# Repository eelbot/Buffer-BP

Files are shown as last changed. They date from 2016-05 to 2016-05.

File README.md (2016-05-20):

# Buffer Booster Pack
## Overview
The Buffer Booster Pack is a simple Booster Pack for TI's LaunchPad development ecosystem that connects eight 5V inputs and eight 5V outputs to the 3.3V inputs and outputs of the LaunchPad. There are indicators and screw terminal connections for each input, as well as screw terminals connections for 5V and GND, to easily interface with proto-typed circuits.

## Pinout
The Buffer Booster Pack is made for a 40-pin booster pack, and follows the Booster Pack Standard. The external input and output numbering is shown on the board.

| External Input | Booster Pack Pin # | | External Output | Booster Pack Pin # |
| :---: | :---: | :--: | :---: | :---: |
| 1 | 7 | | 1 | 38 |
| 2 | 8 | | 2 | 37 |
| 3 | 9 | | 3 | 15 |
| 4 | 10 | | 4 | 14 |
| 5 | 5 | | 5 | 34 |
| 6 | 39 | | 6 | 13 |
| 7 | 40 | | 7 | 12 |
| 8 | 19 | | 8 | 11 |

## Firmware Examples
Two examples are included in the firmware folder. There is one for Energia, which uses standard Booster Pack pinouts, and the other is for the F28069 LaunchPad with Code Composer Studio.

## Power
The Buffer Booster Pack supplies 3.3V to the 3V3 pin of the target Launchpad. The 5V pin is not connected, and the external DC Jack must be connected in order for the Booster Pack to function correctly.

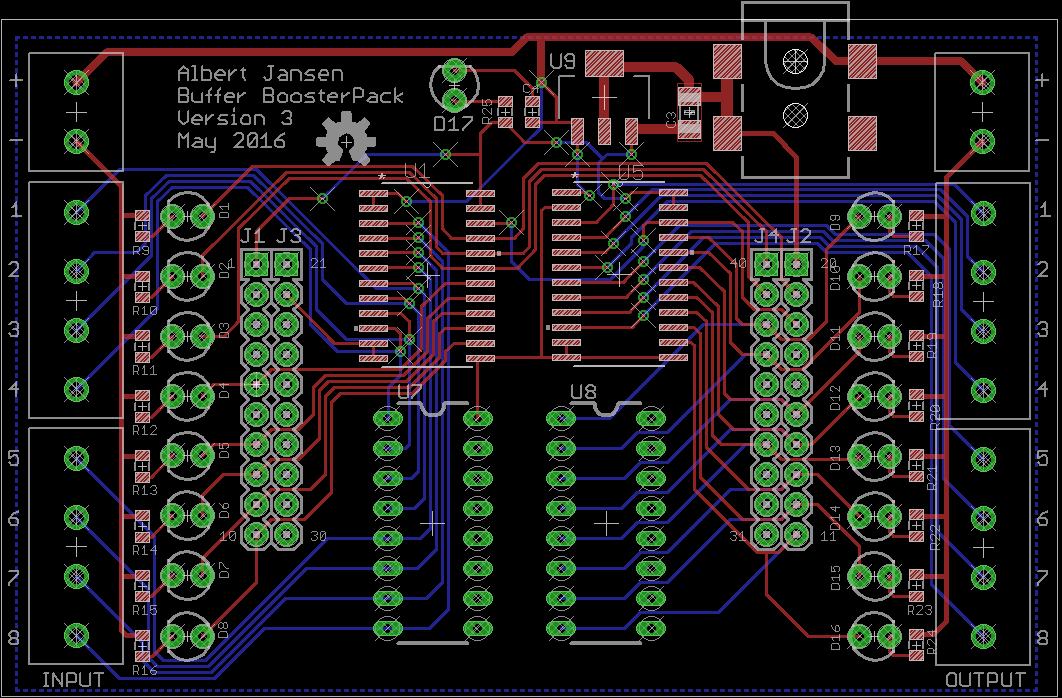
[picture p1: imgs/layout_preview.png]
Board Layout


## To-Do
- Final hardware tests (need to wait until boards arrive)

## License
<br>
This work is licensed under a [Creative Commons Attribution-ShareAlike 3.0 Unported License](http://creativecommons.org/licenses/by-sa/3.0/)

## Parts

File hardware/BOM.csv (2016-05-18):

Part Name | Package | Quantity | Digikey Part Number
2x10 0.1" Female Headers | PTH | 2 | S6106-ND
3mm Blue LED (2mA) | PTH | 17 | 754-1914-ND
330 Resistor | 805 | 17 | RMCF0805JT330RCT-ND
0.47uF Capacitor | 805 | 1 | 399-8100-1-ND
33uF Capacitor | 1206 | 1 | 445-4060-1-ND
1x2 0.2" Screw Terminal | PTH | 2 | ED2609-ND
1x4 0.2" Screw Terminal | PTH | 4 | ED2611-ND
5.5x2.1 Barrel Power Jack | SMD | 1 | CP-002AHPJCT-ND
5V-3.3V LDO | SOT223 | 1 | LM3940IMPX-3.3/NOPBCT-ND
56k Resistor Array (8) | DIP | 2 | 4116R-1-563LF-ND

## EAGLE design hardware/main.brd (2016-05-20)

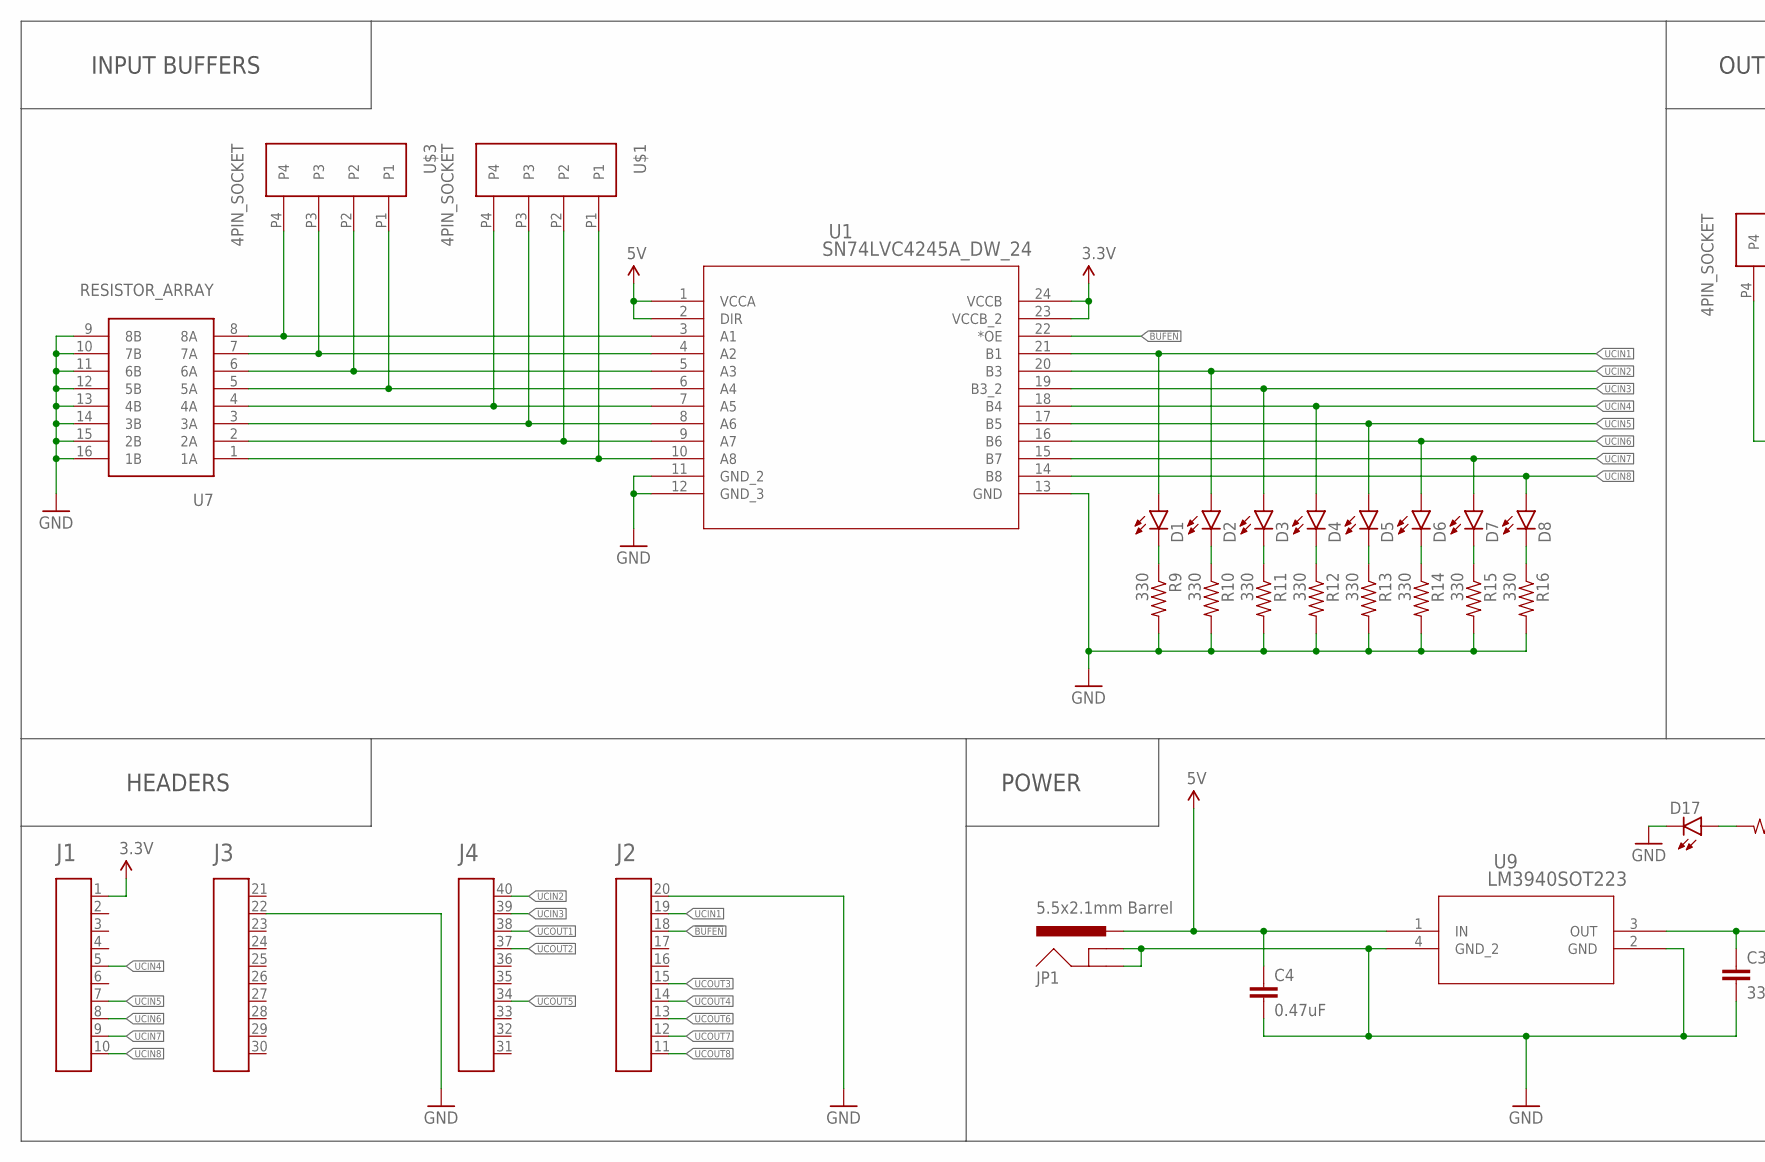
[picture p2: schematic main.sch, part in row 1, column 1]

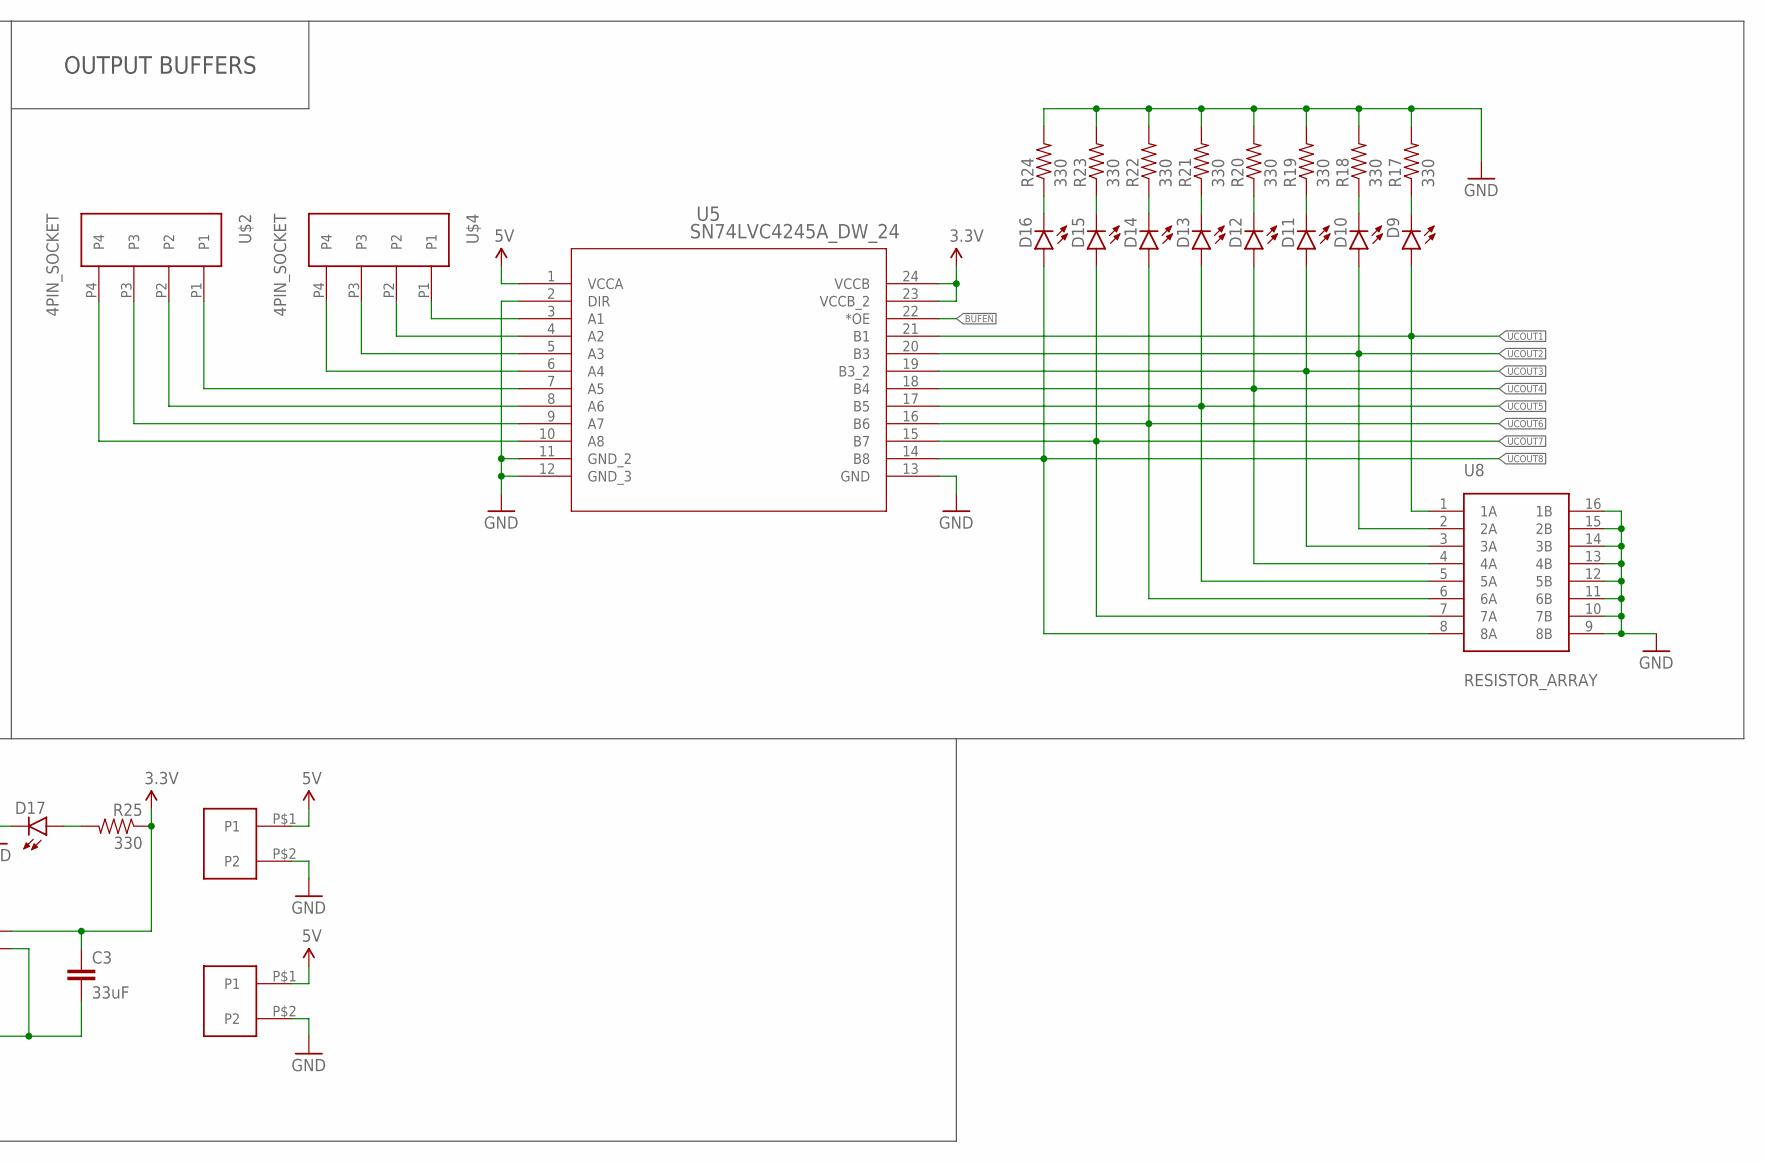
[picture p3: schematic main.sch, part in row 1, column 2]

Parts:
A1: HEADER4X10-BOOSTERPACK; 4X10-BOOSTERPACK
C3: 33uF; 1206
C4: 0.47uF; 0805
D1, D2, D3, D4, D5, D6, D7, D8, D9, D10, D11, D12, D13, D14, D15, D16, D17: LED3MM
JP1: 5.5x2.1mm Barrel; POWER_JACK_SMD
R9, R10, R11, R12, R13, R14, R15, R16, R17, R18, R19, R20, R21, R22, R23, R24, R25: 330; 0805
U1, U5: SN74LVC4245A_DW_24; DW24
U7, U8: RESISTOR_ARRAY; DIL16
U9: LM3940SOT223; DCY
U$1, U$2, U$3, U$4: 4PIN_SOCKET; CONN-4PIN
U$5, U$6: 2PIN_SOCKET; CONN-2PIN

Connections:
3.3V: A1.1, C3.1, R25.1, U1.23 (VCCB_2), U1.24 (VCCB), U5.23 (VCCB_2), U5.24 (VCCB), U9.3 (OUT)
5V: C4.1, JP1.VIN0 (PWR), U1.1 (VCCA), U1.2 (DIR), U5.1 (VCCA), U9.1 (IN), U$5.P$1 (P1), U$6.P$1 (P1)
!BUFEN!: A1.18, U1.22 (*OE), U5.22 (*OE)
GND: A1.20, A1.22, C3.2, C4.2, D17.K (C), JP1.GND (GNDBREAK), JP1.P$4 (GND), R9.2, R10.2, R11.2, R12.2, R13.2, R14.2, R15.2, R16.2, R17.2, R18.2, R19.2, R20.2, R21.2, R22.2, R23.2, R24.2, U1.11 (GND_2), U1.12 (GND_3), U1.13 (GND), U5.2 (DIR), U5.11 (GND_2), U5.12 (GND_3), U5.13 (GND), U7.9 (8B), U7.10 (7B), U7.11 (6B), U7.12 (5B), U7.13 (4B), U7.14 (3B), U7.15 (2B), U7.16 (1B), U8.9 (8B), U8.10 (7B), U8.11 (6B), U8.12 (5B), U8.13 (4B), U8.14 (3B), U8.15 (2B), U8.16 (1B), U9.2 (GND), U9.4 (GND_2), U$5.P$2 (P2), U$6.P$2 (P2)
unnamed: U1.10 (A8), U7.1 (1A), U$1.P1
unnamed: U1.9 (A7), U7.2 (2A), U$1.P2
unnamed: U1.8 (A6), U7.3 (3A), U$1.P3
unnamed: U1.7 (A5), U7.4 (4A), U$1.P4
unnamed: U1.6 (A4), U7.5 (5A), U$3.P1
unnamed: U1.5 (A3), U7.6 (6A), U$3.P2
unnamed: U1.4 (A2), U7.7 (7A), U$3.P3
unnamed: U1.3 (A1), U7.8 (8A), U$3.P4
unnamed: D1.K (C), R9.1
unnamed: D2.K (C), R10.1
unnamed: D3.K (C), R11.1
unnamed: D4.K (C), R12.1
unnamed: D5.K (C), R13.1
unnamed: D6.K (C), R14.1
unnamed: D7.K (C), R15.1
unnamed: D8.K (C), R16.1
unnamed: U5.3 (A1), U$4.P1
unnamed: U5.4 (A2), U$4.P2
unnamed: U5.5 (A3), U$4.P3
unnamed: U5.6 (A4), U$4.P4
unnamed: U5.7 (A5), U$2.P1
unnamed: U5.8 (A6), U$2.P2
unnamed: U5.9 (A7), U$2.P3
unnamed: U5.10 (A8), U$2.P4
unnamed: D9.K (C), R17.1
unnamed: D10.K (C), R18.1
unnamed: D11.K (C), R19.1
unnamed: D12.K (C), R20.1
unnamed: D13.K (C), R21.1
unnamed: D14.K (C), R22.1
unnamed: D15.K (C), R23.1
unnamed: D16.K (C), R24.1
unnamed: D17.A, R25.2
UCIN1: A1.19, D1.A, U1.21 (B1)
UCIN2: A1.40, D2.A, U1.20 (B3)
UCIN3: A1.39, D3.A, U1.19 (B3_2)
UCIN4: A1.5, D4.A, U1.18 (B4)
UCIN5: A1.7, D5.A, U1.17 (B5)
UCIN6: A1.8, D6.A, U1.16 (B6)
UCIN7: A1.9, D7.A, U1.15 (B7)
UCIN8: A1.10, D8.A, U1.14 (B8)
UCOUT1: A1.38, D9.A, U5.21 (B1), U8.1 (1A)
UCOUT2: A1.37, D10.A, U5.20 (B3), U8.2 (2A)
UCOUT3: A1.15, D11.A, U5.19 (B3_2), U8.3 (3A)
UCOUT4: A1.14, D12.A, U5.18 (B4), U8.4 (4A)
UCOUT5: A1.34, D13.A, U5.17 (B5), U8.5 (5A)
UCOUT6: A1.13, D14.A, U5.16 (B6), U8.6 (6A)
UCOUT7: A1.12, D15.A, U5.15 (B7), U8.7 (7A)
UCOUT8: A1.11, D16.A, U5.14 (B8), U8.8 (8A)

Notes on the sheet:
INPUT BUFFERS
HEADERS
OUTPUT BUFFERS
POWER

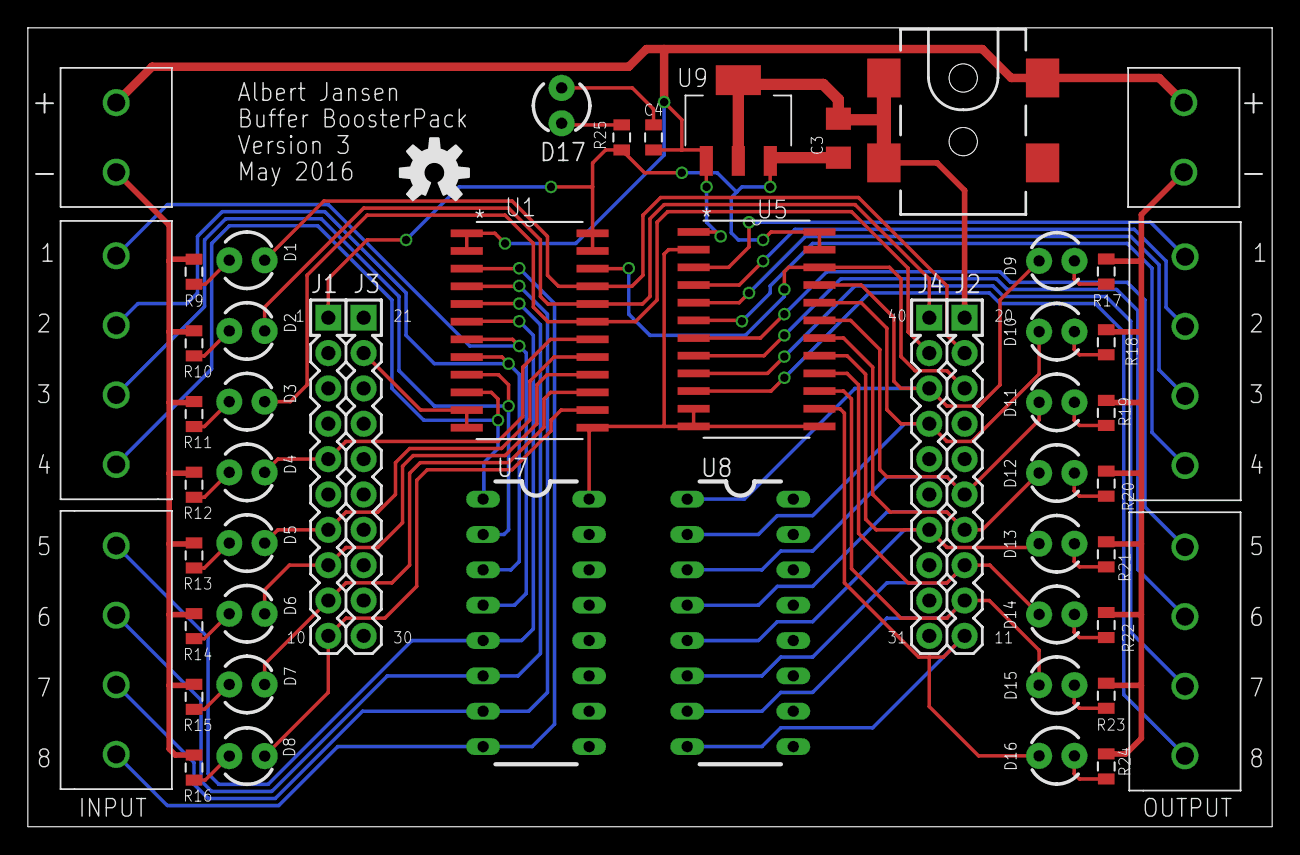
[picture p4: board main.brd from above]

Board: 2 copper layers, 89.4 x 57.4 mm, 50 parts (0 on the bottom side), 53 nets.

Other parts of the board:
U$7: OSHW-LOGO-M

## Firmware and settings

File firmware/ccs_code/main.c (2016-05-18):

#include "DSP28x_Project.h"

/*
 * This program puts the state of the input on the respective output,
 * e.g., if input 4 is high, input 5 is high. The pins are defined from
 * 1-8, e.g. GPIO18 is input 1, GPIO22 is input 2, etc.
 */

void main(void) {

	// Pin configuration
	EALLOW;

	// Inputs
	GpioCtrlRegs.GPADIR.bit.GPIO18 = 0;
	GpioCtrlRegs.GPADIR.bit.GPIO22 = 0;
	GpioCtrlRegs.GPBDIR.bit.GPIO33 = 0;
	GpioCtrlRegs.GPBDIR.bit.GPIO32 = 0;

	GpioCtrlRegs.GPADIR.bit.GPIO12 = 0;
	GpioCtrlRegs.GPADIR.bit.GPIO1 = 0;
	GpioCtrlRegs.GPADIR.bit.GPIO0 = 0;
	GpioCtrlRegs.GPADIR.bit.GPIO19 = 0;

	// Outputs
	GpioCtrlRegs.GPADIR.bit.GPIO2 = 1;
	GpioCtrlRegs.GPADIR.bit.GPIO3 = 1;
	GpioCtrlRegs.GPADIR.bit.GPIO16 = 1;
	GpioCtrlRegs.GPADIR.bit.GPIO17 = 1;

	GpioCtrlRegs.GPADIR.bit.GPIO13 = 1;
	GpioCtrlRegs.GPBDIR.bit.GPIO50 = 1;
	GpioCtrlRegs.GPBDIR.bit.GPIO51 = 1;
	GpioCtrlRegs.GPBDIR.bit.GPIO55 = 1;
	EDIS;
	
	while(1){
		// Check input 1
		if(GpioDataRegs.GPADAT.bit.GPIO18){
			GpioDataRegs.GPASET.bit.GPIO2 = 1;
		}
		else{
			GpioDataRegs.GPACLEAR.bit.GPIO2 = 1;
		}

		// Check input 2
		if(GpioDataRegs.GPADAT.bit.GPIO22){
			GpioDataRegs.GPASET.bit.GPIO3 = 1;
		}
		else{
			GpioDataRegs.GPACLEAR.bit.GPIO3 = 1;
		}

		// Check input 3
		if(GpioDataRegs.GPBDAT.bit.GPIO33){
			GpioDataRegs.GPASET.bit.GPIO16 = 1;
		}
		else{
			GpioDataRegs.GPACLEAR.bit.GPIO16 = 1;
		}

		// Check input 4
		if(GpioDataRegs.GPBDAT.bit.GPIO32){
			GpioDataRegs.GPASET.bit.GPIO17 = 1;
		}
		else{
			GpioDataRegs.GPACLEAR.bit.GPIO17 = 1;
		}

		// Check input 5
		if(GpioDataRegs.GPADAT.bit.GPIO12){
			GpioDataRegs.GPASET.bit.GPIO13 = 1;
		}
		else{
			GpioDataRegs.GPACLEAR.bit.GPIO13 = 1;
		}

		// Check input 6
		if(GpioDataRegs.GPADAT.bit.GPIO1 == 1){
			GpioDataRegs.GPBSET.bit.GPIO50 = 1;
		}
		else{
			GpioDataRegs.GPBCLEAR.bit.GPIO50 = 1;
		}

		// Check input 7
		if(GpioDataRegs.GPADAT.bit.GPIO18 == 1){
			GpioDataRegs.GPBSET.bit.GPIO51 = 1;
		}
		else{
			GpioDataRegs.GPBCLEAR.bit.GPIO51 = 1;
		}

		// Check input 8
		if(GpioDataRegs.GPADAT.bit.GPIO19 == 1){
			GpioDataRegs.GPBSET.bit.GPIO55 = 1;
		}
		else{
			GpioDataRegs.GPBCLEAR.bit.GPIO55 = 1;
		}
	}
}

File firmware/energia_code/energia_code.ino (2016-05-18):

// Pin definitions for easy sketch modification
// INPUTS
const int in1 = 7;
const int in2 = 8;
const int in3 = 9;
const int in4 = 10;
const int in5 = 5;
const int in6 = 39;
const int in7 = 40;
const int in8 = 19;

// OUTPUTS
const int out1 = 38;
const int out2 = 37;
const int out3 = 15;
const int out4 = 14;
const int out5 = 34;
const int out6 = 13;
const int out7 = 12;
const int out8 = 11;

// Buffer enable
const int buffer_enable = 18;


void setup()
{
  // Turn off buffers to start (buffer_enable is active low)
  pinMode(buffer_enable, OUTPUT);
  digitalWrite(buffer_enable, HIGH);
  
  // Inputs
  pinMode(in1, INPUT);
  pinMode(in2, INPUT);
  pinMode(in3, INPUT);
  pinMode(in4, INPUT);
  pinMode(in5, INPUT);
  pinMode(in6, INPUT);
  pinMode(in7, INPUT);
  pinMode(in8, INPUT);
  
  // Outputs
  pinMode(out1, OUTPUT);
  pinMode(out2, OUTPUT);
  pinMode(out3, OUTPUT);
  pinMode(out4, OUTPUT);
  pinMode(out5, OUTPUT);
  pinMode(out6, OUTPUT);
  pinMode(out7, OUTPUT);
  pinMode(out8, OUTPUT);
  
  // Initialize all outputs to 0
  digitalWrite(out1, LOW);
  digitalWrite(out2, LOW);
  digitalWrite(out3, LOW);
  digitalWrite(out4, LOW);
  digitalWrite(out5, LOW);
  digitalWrite(out6, LOW);
  digitalWrite(out7, LOW);
  digitalWrite(out8, LOW);
  
  // Enable buffers
  digitalWrite(buffer_enable, LOW);
}

void loop()
{
  /**
  ** The following example transfers the input states directly
  ** to the output states. Effectively, a 5V buffer, simply to
  ** demonstrate basic functionality.
  **/
  
  if (digitalRead(in1) == HIGH){ digitalWrite(out1, HIGH); }
  else { digitalWrite(out1, LOW); }

  if (digitalRead(in2) == HIGH){ digitalWrite(out2, HIGH); }
  else { digitalWrite(out2, LOW); }

  if (digitalRead(in3) == HIGH){ digitalWrite(out3, HIGH); }
  else { digitalWrite(out3, LOW); }

  if (digitalRead(in4) == HIGH){ digitalWrite(out4, HIGH); }
  else { digitalWrite(out4, LOW); }

  if (digitalRead(in5) == HIGH){ digitalWrite(out5, HIGH); }
  else { digitalWrite(out5, LOW); }

  if (digitalRead(in6) == HIGH){ digitalWrite(out6, HIGH); }
  else { digitalWrite(out6, LOW); }

  if (digitalRead(in7) == HIGH){ digitalWrite(out7, HIGH); }
  else { digitalWrite(out7, LOW); }

  if (digitalRead(in8) == HIGH){ digitalWrite(out8, HIGH); }
  else { digitalWrite(out8, LOW); }  
}

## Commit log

2016-04-03 Designed schematic and routed board.
    [main.brd, main.sch]
2016-04-03 Cleaned up board. Cleaned up schematic. No structural or electrical changes
    [main.brd, main.sch]
2016-04-04 Minor fixes and gerber generation
    [main.brd]
2016-04-04 Gerbers generated - Elecrow 2 layers
2016-04-15 Added pulldown resistors on inputs. Updated version number
    [main.brd, main.sch]
2016-05-11 Re-routed and updated board and schematic
    [main.brd, main.sch]
2016-05-11 Cleaned up and finalized board design
    [main.brd]
2016-05-11 Updated with DRC modifications
    [main.brd, main.sch]
2016-05-18 Minor component value changes. Added a BOM
    [BOM.csv, main.brd, main.sch]
2016-05-18 Removed 'ENEXT', as it is not needed
    [main.brd, main.sch]
2016-05-18 Added helpful silkscreen markings
    [main.brd]
2016-05-20 Small power routing update (Power the target launchpad via 3.3V connection)
    [main.brd]
2016-05-20 Finalized documentation and added open source licensing and logos
    [main.brd]

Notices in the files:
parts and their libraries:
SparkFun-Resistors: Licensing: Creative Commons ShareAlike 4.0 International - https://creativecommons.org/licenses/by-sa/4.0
